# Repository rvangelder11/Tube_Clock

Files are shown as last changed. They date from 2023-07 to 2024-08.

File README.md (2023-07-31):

# Tube Clock
## Clock in perpex tube

This clock was build to fit in a perpex tube and to indicate the time in text instead of numbers.
It also displays the weather and the latest news in a ticker mode fashion.
Currently it displays the time in Dutch language, but that could easily be adapted to other languages 



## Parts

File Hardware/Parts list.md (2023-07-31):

- 54 cm of perspex tube, outside diameter 41 mm, inside 36 mm. (I could only buy minimum length of 2m)
- 4x Max7219 Dot-Matrixmodule for Microcontroller 4 In one Display (AliExpress)
- 1x ESP8266 Wemos D1
- power supply with a micro SD connector to feed the displays and the ESP8266
- Optional: 2x brackets 3D printed to cover the sides

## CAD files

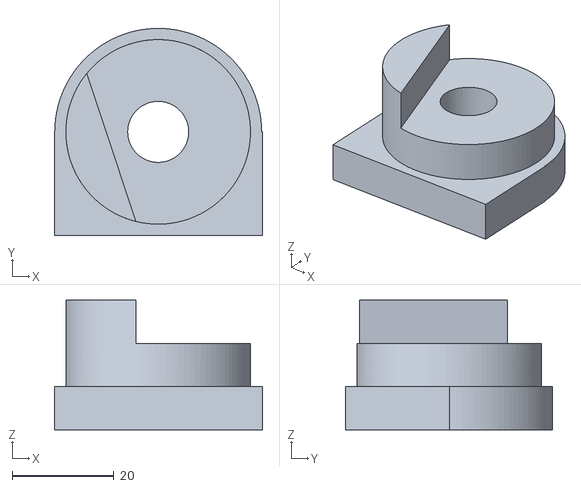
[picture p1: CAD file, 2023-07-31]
Hardware/dop voor perspex buis v5.stl
40.9 x 40.7 x 25.5

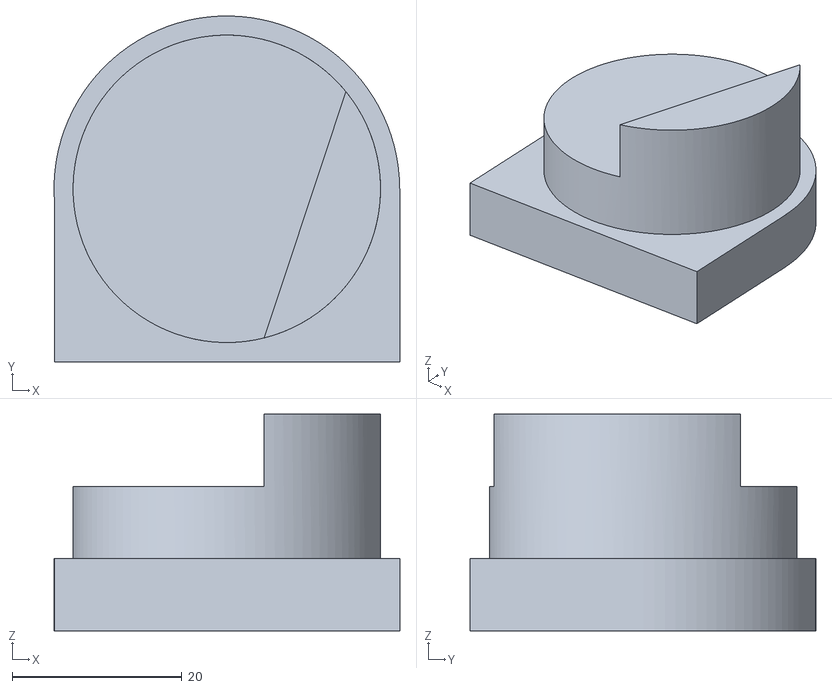
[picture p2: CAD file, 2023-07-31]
Hardware/dop voor perspex buis_Component1(Mirror) v1.stl
40.7 x 40.7 x 25.5

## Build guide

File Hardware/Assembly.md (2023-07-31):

- Chain all modules together (VCC to VCC, GND to GND, DOUT to DIN, CS to CS, CLK to CLK)
- Connect D5 of ESP8266 to CLK on the most right Max7219 module 
- Connect D6 of ESP8266 to DIN on the most right Max7219 module 
- Connect D7 of ESP8266 to CS on the most right Max7219 module
- Connect 5V of ESP8266 to VCC on the most right Max7219 module
- Connect GND of ESP8266 to GND on the most right Max7219 module
- Load software on the ESP8266
- Connect to power source
- The ESP8266 will initially start up as an Access Point with the name "Lichtkrant"
- Connect to the Access point with the name "Lichtkrant" (without a password)
- Browse to 192.168.4.1
  
 Wifimanager

- Fill in Wifi name and password.
- After success, the clock starts
- The ESP8266 can be mounted on the back of the right MAX7219 module with double sided tape
  


- The whole assembly can be shifted in the perspex tube
- Optionally close the tube on both sides with a 3D printed bracket (dop voor perspex buis v5.stl and dop voor perspex buis_Component1(Mirror) v1.stl)
  


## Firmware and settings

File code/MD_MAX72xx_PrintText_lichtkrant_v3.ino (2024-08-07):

// Use the MD_MAX72XX library to Print some text on the display
// This code puts the time in dutch text on a max7219 display and shows news, weather forecasts and rain messages in between
#include <WiFiManager.h>
#include <PubSubClient.h>
#include <Wire.h>
#include <ESP8266WiFi.h>
#include <MD_MAX72xx.h>
#include <SPI.h>
#include <ezTime.h>
#include <MD_Parola.h>
#include <ESP8266mDNS.h>
#include <WiFiUdp.h>
#include <ArduinoOTA.h>
#include "Parola_Fonts_data.h"

// Define the number of devices we have in the chain and the hardware interface
#define HARDWARE_TYPE MD_MAX72XX::FC16_HW
#define MAX_DEVICES 16

#define CLK_PIN   D5 //13  // or SCK
#define DATA_PIN  D7 //11  // or MOSI
#define CS_PIN    D6 //10  // or SS Normaal D8, maar die is kapot
#define  DELAYTIME  100  // wait a bit between updates of the display in milliseconds 

// SPI hardware interface
//MD_MAX72XX mx = MD_MAX72XX(HARDWARE_TYPE, CS_PIN, MAX_DEVICES);
// Arbitrary pins
//MD_MAX72XX mx = MD_MAX72XX(HARDWARE_TYPE, DATA_PIN, CLK_PIN, CS_PIN, MAX_DEVICES);
MD_Parola P = MD_Parola(HARDWARE_TYPE, CS_PIN, MAX_DEVICES);

// Text parameters
#define CHAR_SPACING  1 // number of pixels between characters. 1 is very tight

#define BUF_SIZE  500 // Global message buffers shared by Serial and Scrolling functions
char message[BUF_SIZE];
char messageTemp[BUF_SIZE];
char tijd_tekst[50];
char tijd_tekst_oud[50];
char* HostName = "Lichtkrant";
boolean WifiConnected = false;

// MQTT Broker IP address
const char* mqtt_server = "FILL IN THE IP OF YOUR MQTT SERVER";
Timezone myTZ;

WiFiClient espLichtkrant;
PubSubClient client(espLichtkrant);

uint8_t SmallSpace[] = { 1, 0 }; // Reduced the space to one column, to make the text fit on the display

void setup() {
  unsigned long startmillis;
  P.begin();
  P.setIntensity(1);
  P.addChar(' ', SmallSpace);
  P.print("   wait for wifi connect");
  startmillis = millis();
  setup_wifi();
  Serial.printf("Setup Wifi took: %u ms\n", millis() - startmillis);
  startmillis = millis();
  P.print("   wait for MQTT connect");
  client.setServer(mqtt_server, 1883);
  client.setCallback(callback);
  Serial.printf("Setup MQTT took: %u ms\n", millis() - startmillis);
  Serial.println("[MD_MAX72XX Message Display]");
  Serial.println("wait for time sync");
  P.print(" wait for time sync");
  startmillis = millis();
  waitForSync();
  Serial.printf("Time sync took: %u ms\n", millis() - startmillis);
  P.print("  time synced");
  if (!myTZ.setCache(0)) myTZ.setLocation(F("nl"));
}

void loop() {
  events();
  if (!client.connected()) {
    reconnect();
  }
  client.loop();
  if (myTZ.hour() == 7 && myTZ.minute() == 00 && myTZ.second() == 0)ESP.restart();
  ArduinoOTA.handle();
  NL_tijd_tekst(myTZ.minute(), myTZ.hour(), tijd_tekst);
  if (P.displayAnimate() and strcmp(tijd_tekst, tijd_tekst_oud) != 0) { // animates and returns true when an animation is completed
    P.displayText(tijd_tekst, PA_CENTER, 0, 0, PA_PRINT, PA_NO_EFFECT);
    strcpy(tijd_tekst_oud, tijd_tekst);
  }
}

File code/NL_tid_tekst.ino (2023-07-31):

void NL_tijd_tekst(int minuut, int uur, char tekst[50]) {
  char *getal[15] = {"twaalf", "één", "twee", "drie", "vier", "vijf", "zes", "zeven", "acht", "negen", "tien", "elf", "twaalf", "dertien", "veertien"};
  if (uur > 12) uur = uur - 12; // we tellen tot twaalf en gaan dan weer naar 1
  if (uur == 12 and minuut > 15) uur = 0; // na 12:15 verwijzen we naar 1 uur. omdat er dan altijd 1 bij wordt opgeteld, moet hier nul staan
  if (minuut == 0) sprintf(tijd_tekst, "%s uur", getal[uur]);
  if (minuut > 0 and minuut < 15) sprintf(tijd_tekst, "%s over %s", getal[minuut], getal[uur]);
  if (minuut == 15) sprintf(tijd_tekst, "kwart over %s", getal[uur]);
  if (minuut > 15 and minuut < 30) sprintf(tijd_tekst, "%s voor half %s", getal[30 - minuut], getal[uur + 1]);
  if (minuut == 30) sprintf(tijd_tekst, "half %s", getal[uur + 1]);
  if (minuut > 30 and minuut < 45) sprintf(tijd_tekst, "%s over half %s", getal[minuut - 30], getal[uur + 1]);
  if (minuut == 45) sprintf(tijd_tekst, "kwart voor %s", getal[uur + 1]);
  if (minuut > 45 and minuut <= 59) sprintf(tijd_tekst, "%s voor %s", getal[60 - minuut], getal[uur + 1]);
  utf8AsciiString(tekst); // zet diacryten om van UTF8 naar exteded Ascii
}
